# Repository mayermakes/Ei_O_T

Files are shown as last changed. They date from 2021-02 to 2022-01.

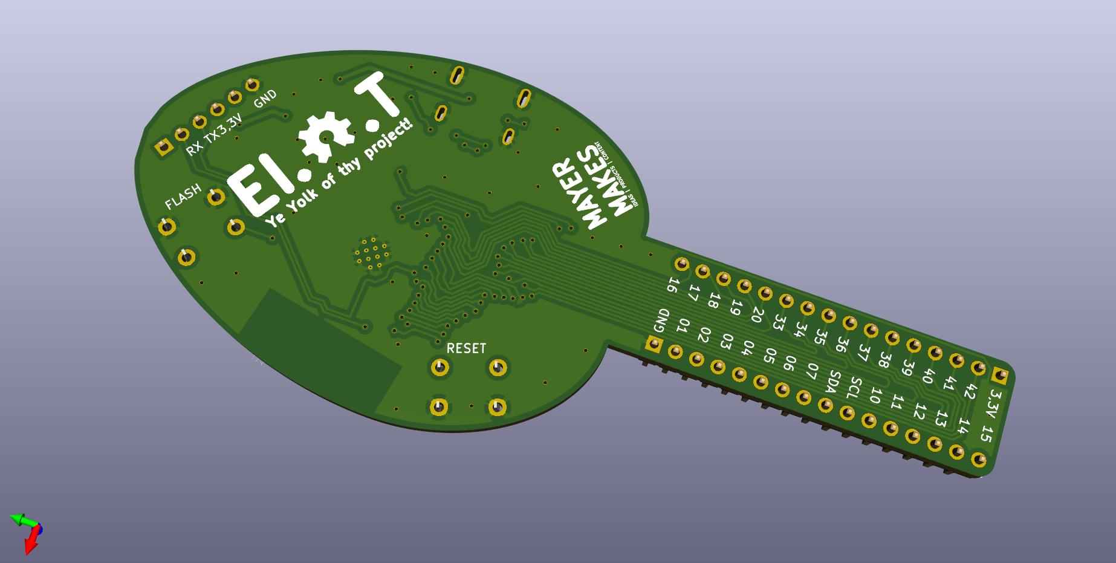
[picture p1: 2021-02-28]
GreenEggs_and_Clem.jpg

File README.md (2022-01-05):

# Ei_O_T
Breadboard Friendly ESP32-S2 Development Kit / Breakout

All EI.O.T Boards are manufactured in either Europe or USA. There are NO genuine Boards made in Asia, and there probably never will be.
This is necessary to ensure quality and safety for the applications developed with our Development Kits and breakout boards.
USB-OTG functionality is built in Hardware wise. 
The Board can be assembled in two ways allowing dominantly left and right handed Developers to optimally use it, also by flipping it upside down you can choose to have the USB cable stick out the top or bottom.

Safety and Handling Notice: 
This product is exclusivelly intended as an utility device for development under laboratory conditions. For use or operation specialist knowledge is required.
Assembly by yourself as askilled technician is required. The provided Firmware is only example code to confirm a correctly executed flashing process.

The project is Licensed CC-BY-SA, the Provided Gerbers are marked with registered Trademarks owned by the original developer or IP owners.
Violation of these rights is not covered by the Open source license or any other license.
If you want to manufacture the Boards for your own private use, you can freely do so. If you intent to bring this design into circulation of any kind you can apply for a distribution license and will be provided an individual version.

The Circuitpython firmware is provided under CC_BY_SA license adhering to the original file it was based on.
You need to follow this guide to be able to flash it:
https://circuitpython.readthedocs.io/en/6.1.x/ports/esp32s2/README.html

For usage with the Arduino IDE please follow the latest tutorial to install the ESP32S2 based boards on Arduino IDE.
To programm the board please choose "ESP32S2DevModule" from the boards list.
Put the board into download mode by holding down the Flash button while pressing reset.
EI.O.T does not automatically reset by design, you need to push the reset button yourself, this is to avoid serial transmittion errors while developing IOT applications.

This evaluation board/kit is intended for use for engineering development, evaluation or demonstration use only. It is not considered by MAYER MAKES e.U. to be a product for End-user /consumer use.  Therefore it may not meet those requirements and is only suitable for use by technically skilled professionals.****

The Files and Documentation are provided as is without any warranty.
MAYER MAKES is an internationally registered Trademark of MAYER MAKES e.U., unauthorized use is prohibited

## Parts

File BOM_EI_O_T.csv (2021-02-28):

Source: | /media/mayermakes/b79b1a1f-57e0-435e-a345-7f3b9296dbeb/kicad/EI_O_T/GreenEggs_and_Clem/GreenEggs_and_Clem.sch
Date: | Fr 26 Feb 2021 21:29:43
Tool: | Eeschema 5.1.5+dfsg1-2build2
Generator: | /usr/share/kicad/plugins/bom_csv_grouped_by_value.py
Component Count: | 16
Individual Components:
Collated Components:
Item | Qty | Reference(s) | Value | LibPart | Footprint | Manufacturer Partnumber | Manufacturer | Supplier | Order Number | Remarks
1 | 1 | C1 | 0,1uF | Device:C | Capacitor_SMD:C_0603_1608Metric_Pad1.05x0.95mm_HandSolder | ~ | Generic
2 | 1 | C2 | 10uF | Device:C | Capacitor_SMD:C_0603_1608Metric_Pad1.05x0.95mm_HandSolder | ~ | Generic
3 | 1 | D1 | LED 0603 | Device:LED | LED_SMD:LED_0603_1608Metric_Pad1.05x0.95mm_HandSolder | ~ | Generic
4 | 1 | J1 | 105450-0101 | 105450-0101:105450-0101 | Molex_USB-C:MOLEX_105450-0101 | 105450-0101 | Molex | Farnell | 2524076 | USB Shielded I/O Receptacle; Type C; Right Angle; Surface Mount; Gold over Nickel
5 | 1 | J2 | Conn_01x06_Female | Connector:Conn_01x06_Female | Connector_PinHeader_2.54mm:PinHeader_1x06_P2.54mm_Vertical | ~ | Generic
6 | 2 | J3, J4 | Conn_01x16 | Connector_Generic:Conn_01x16 | Connector_PinHeader_2.54mm:PinHeader_1x16_P2.54mm_Vertical | ~ | Generic
7 | 2 | R1, R2 | 5k1 | Device:R | Resistor_SMD:R_0603_1608Metric_Pad1.05x0.95mm_HandSolder | ~ | Generic
8 | 2 | R3, R4 | 10k | Device:R | Resistor_SMD:R_0603_1608Metric_Pad1.05x0.95mm_HandSolder | ~ | Generic
9 | 1 | R5 | 220 | Device:R | Resistor_SMD:R_0603_1608Metric_Pad1.05x0.95mm_HandSolder | ~ | Generic
10 | 1 | SW1 | reset | Switch:SW_Push | Button_Switch_THT:SW_PUSH_6mm | ~ | Generic
11 | 1 | SW2 | flash | Switch:SW_Push | Button_Switch_THT:SW_PUSH_6mm | ~ | Generic
12 | 1 | U1 | ESP32-S2-WROOM | ESP32-S2-WROOM:ESP32-S2-WROOM | ESP32S2:XCVR_ESP32-S2-WROOM | ESP32-S2-WROOM(M22S2H3200PH3Q0) | Espressif | Mouser | 356-ESP32S2WRM3200PH
13 | 1 | U2 | MCP1825S-3302E/DB | Regulator_Linear:MCP1825S | Package_TO_SOT_SMD:SOT-223-3_TabPin2 | MCP1825S-3302E/DB | Mikrochip | Farnell | 1578404

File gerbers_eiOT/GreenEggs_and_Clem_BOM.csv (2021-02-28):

ID | Bezeichner | Gehäuse | Stückzahl | Bezeichnung | Anbieter und Referenz
1 | REF** | OSHW-Symbol_6.7x6mm_SilkScreen | 1 | OSHW-Symbol_6.7x6mm_SilkScreen | DO NOT POPULATE
2 | U1 | XCVR_ESP32-S2-WROOM | 1 | ESP32-S2-WROOM | https://www.mouser.at/ProductDetail/Espressif-Systems/ESP32-S2-WROOMM22S2H3200PH3Q0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
3 | C1 | C_0603_1608Metric_Pad1.05x0.95mm_HandSolder | 1 | 0,1uF | https://export.farnell.com/avx/06031c104kat2a/cap-0-1-f-100v-10-x7r-0603/dp/2749806RL?st=0,1uf%200603
4 | C2 | C_0603_1608Metric_Pad1.05x0.95mm_HandSolder | 1 | 10uF | https://export.farnell.com/avx/0603zd106mat2a/cap-10-f-10v-20-x5r-0603/dp/1867954?st=10uf%200603
5 | D1 | LED_0603_1608Metric_Pad1.05x0.95mm_HandSolder | 1 | LED 0603 | https://export.farnell.com/kingbright/kp-1608syck/led-0603-150mcd-yellow/dp/2290330RL?st=led%200603
6 | J1 | MOLEX_105450-0101 | 1 | 105450-0101 | https://export.farnell.com/molex/105450-0101/usb-conn-3-1-usb-type-c-rcpt-surface/dp/2524076?st=105450-0101
7 | J2 | PinHeader_1x06_P2.54mm_Vertical | 1 | Conn_01x06_Female | DO NOT POPULATE
8 | R1,R2 | R_0603_1608Metric_Pad1.05x0.95mm_HandSolder | 2 | 5k1 | https://export.farnell.com/panasonic/erj3ekf5101v/res-5k1-1-0-1w-0603-thick-film/dp/2059378?st=5k1%200603
9 | R3,R4 | R_0603_1608Metric_Pad1.05x0.95mm_HandSolder | 2 | 10k | https://export.farnell.com/vishay/crcw060310k0fkec/res-aec-q200-thick-film-10k-0603/dp/2906637?st=10k%200603
10 | R5 | R_0603_1608Metric_Pad1.05x0.95mm_HandSolder | 1 | 220 | https://export.farnell.com/vishay/crcw0603220rfkea/res-220r-1-0-1w-0603-thick-film/dp/1652857RL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
11 | RESET | SW_PUSH_6mm | 1 | reset | https://export.farnell.com/omron/b3f-1000/switch-spno-0-05a-24v-tht-0-98n/dp/176432?st=omron%20push%20button
12 | FLASH | SW_PUSH_6mm | 1 | flash | https://export.farnell.com/omron/b3f-1000/switch-spno-0-05a-24v-tht-0-98n/dp/176432?st=omron%20push%20button
13 | U2 | SOT-223-3_TabPin2 | 1 | MCP1825S-3002E/DB | https://export.farnell.com/microchip/mcp1825s-3002e-db/ic-ldo-3-0v-500ma-sot-223-3/dp/1578402?st=mcp1825s
14 | J3,J4 | PinHeader_1x16_P2.54mm_Vertical | 2 | Conn_01x16 | https://export.farnell.com/amp-te-connectivity/1-826629-6/header-straight-16way/dp/1248124?st=pinheader%202.54

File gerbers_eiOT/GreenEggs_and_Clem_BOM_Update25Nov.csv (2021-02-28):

ID | Bezeichner | Gehäuse | Stückzahl | Bezeichnung | Anbieter und Referenz
1 | REF** | OSHW-Symbol_6.7x6mm_SilkScreen | 1 | OSHW-Symbol_6.7x6mm_SilkScreen | DO NOT POPULATE
2 | U1 | XCVR_ESP32-S2-WROOM | 1 | ESP32-S2-WROOM | https://www.mouser.at/ProductDetail/Espressif-Systems/ESP32-S2-WROOMM22S2H3200PH3Q0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
3 | C1 | C_0603_1608Metric_Pad1.05x0.95mm_HandSolder | 1 | 0,1uF | local brand 0603(imperial) 0,1uF ceramic cap
4 | C2 | C_0603_1608Metric_Pad1.05x0.95mm_HandSolder | 1 | 10uF | local brand 0603(imperial) 10uF ceramic cap
5 | D1 | LED_0603_1608Metric_Pad1.05x0.95mm_HandSolder | 1 | LED 0603 | local brand 0603(imperial) yellow LED 20ma
6 | J1 | MOLEX_105450-0101 | 1 | 105450-0101 | https://export.farnell.com/molex/105450-0101/usb-conn-3-1-usb-type-c-rcpt-surface/dp/2524076?st=105450-0101
7 | J2 | PinHeader_1x06_P2.54mm_Vertical | 1 | Conn_01x06_Female | DO NOT POPULATE
8 | R1,R2 | R_0603_1608Metric_Pad1.05x0.95mm_HandSolder | 2 | 5k1 | local brand 0603(imperial) 5k1 resistor
9 | R3,R4 | R_0603_1608Metric_Pad1.05x0.95mm_HandSolder | 2 | 10k | local brand 0603(imperial) 10k resistor
10 | R5 | R_0603_1608Metric_Pad1.05x0.95mm_HandSolder | 1 | 220 | local brand 0603(imperial) 220 ohm resistor
11 | RESET | SW_PUSH_6mm | 1 | reset | local brand tht tactile pushbutton DO NOT POPULATE
12 | FLASH | SW_PUSH_6mm | 1 | flash | local brand tht tactile pushbutton DO NOT POPULATE
13 | U2 | SOT-223-3_TabPin2 | 1 | MCP1825S-3002E/DB | https://export.farnell.com/microchip/mcp1825s-3002e-db/ic-ldo-3-0v-500ma-sot-223-3/dp/1578402?st=mcp1825s
14 | J3,J4 | PinHeader_1x16_P2.54mm_Vertical | 2 | Conn_01x16 | local Brand 2,54mm pin header 16 pins DO NOT POPULATE

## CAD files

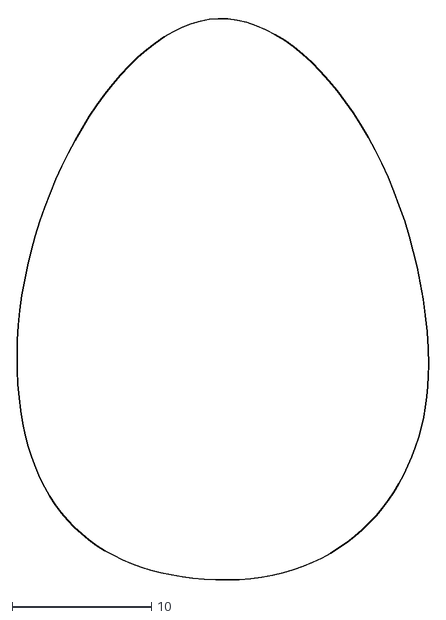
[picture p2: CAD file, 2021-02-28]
egg.dxf
29.8 x 40.6

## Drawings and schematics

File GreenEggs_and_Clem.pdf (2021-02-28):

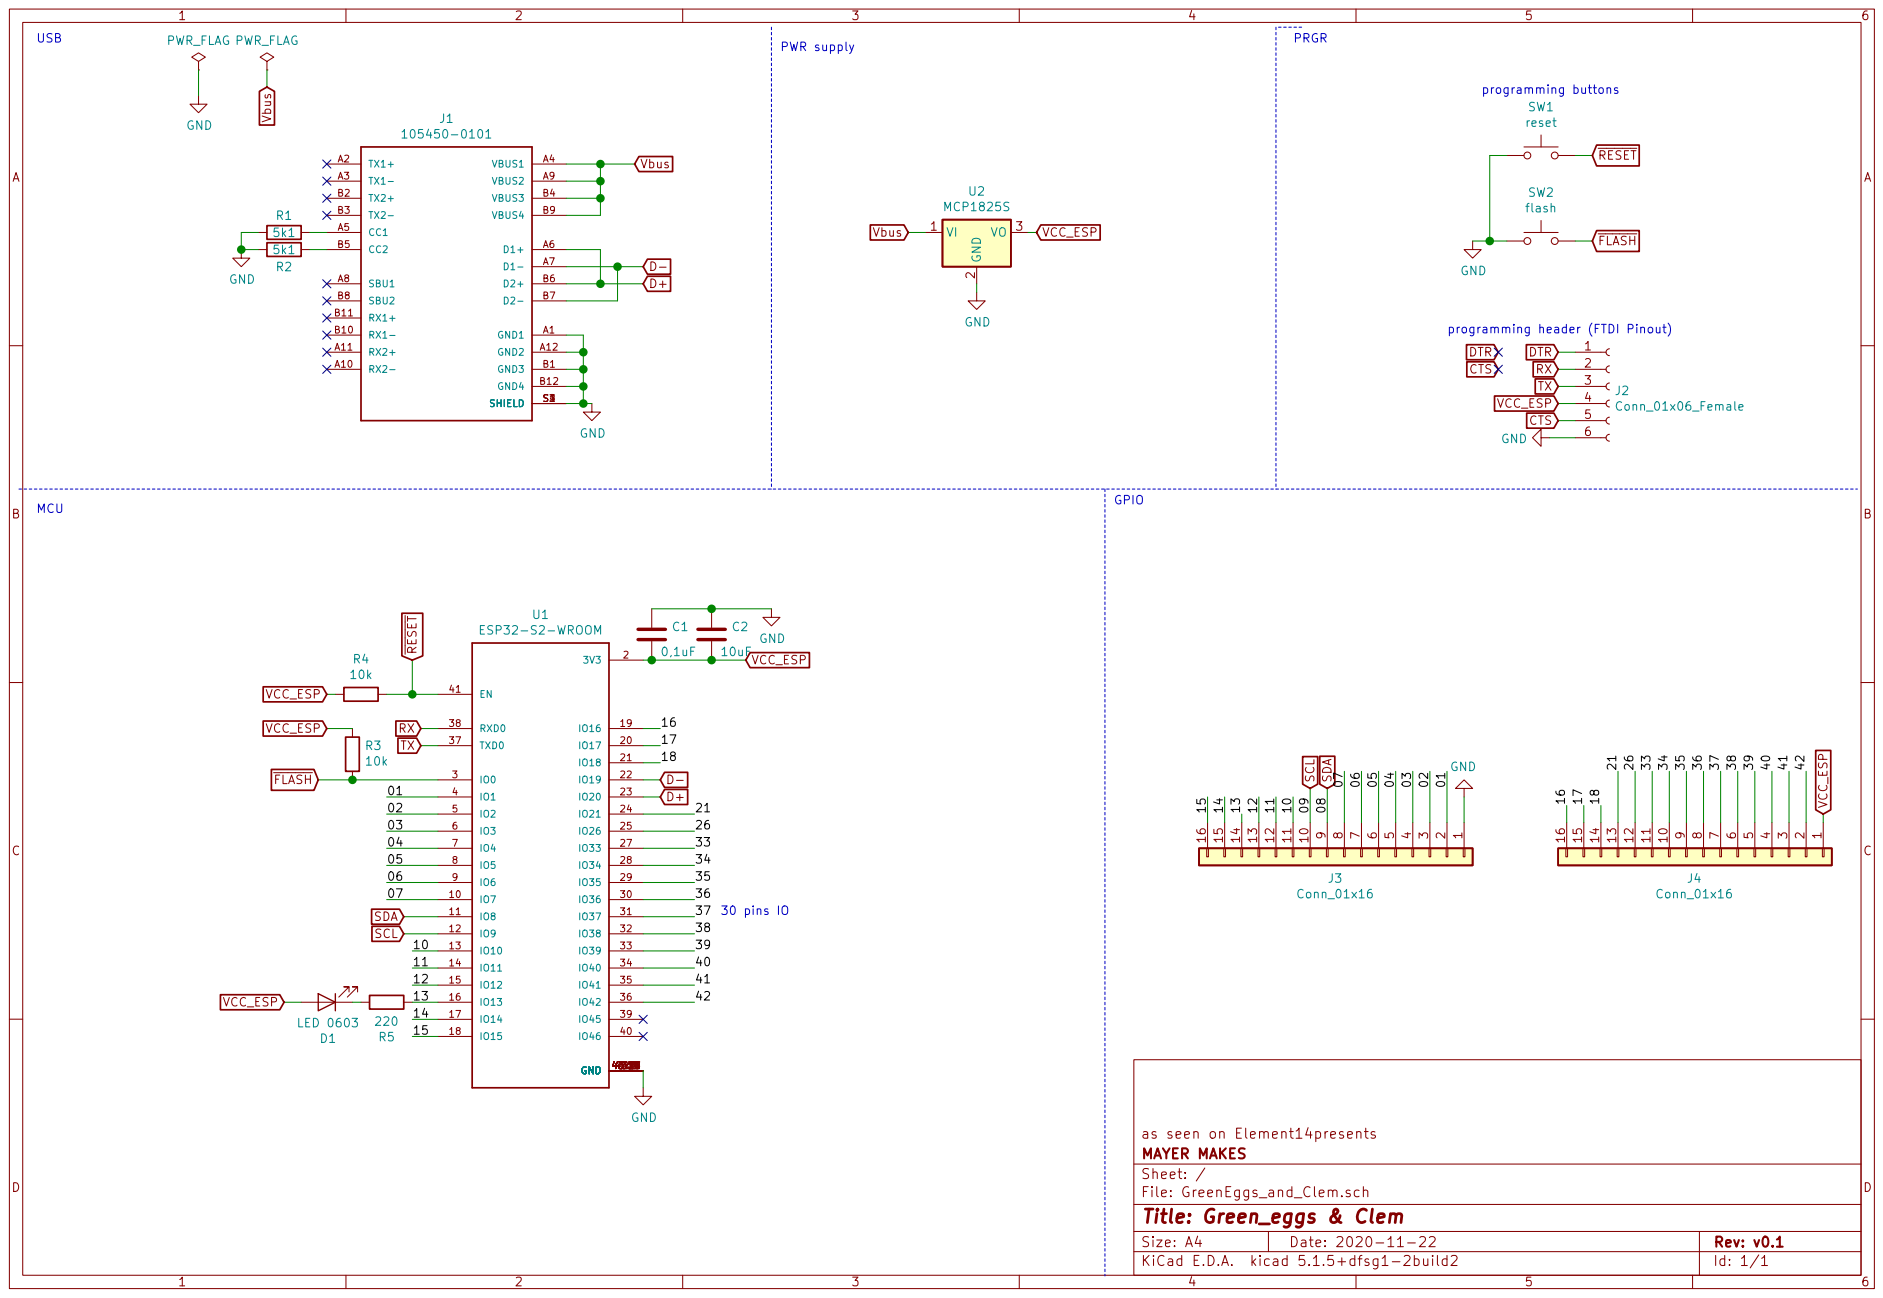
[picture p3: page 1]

programming header (FTDI Pinout)

File: GreenEggs_and_Clem.sch Sheet: / MAYER MAKES as seen on Element14presents

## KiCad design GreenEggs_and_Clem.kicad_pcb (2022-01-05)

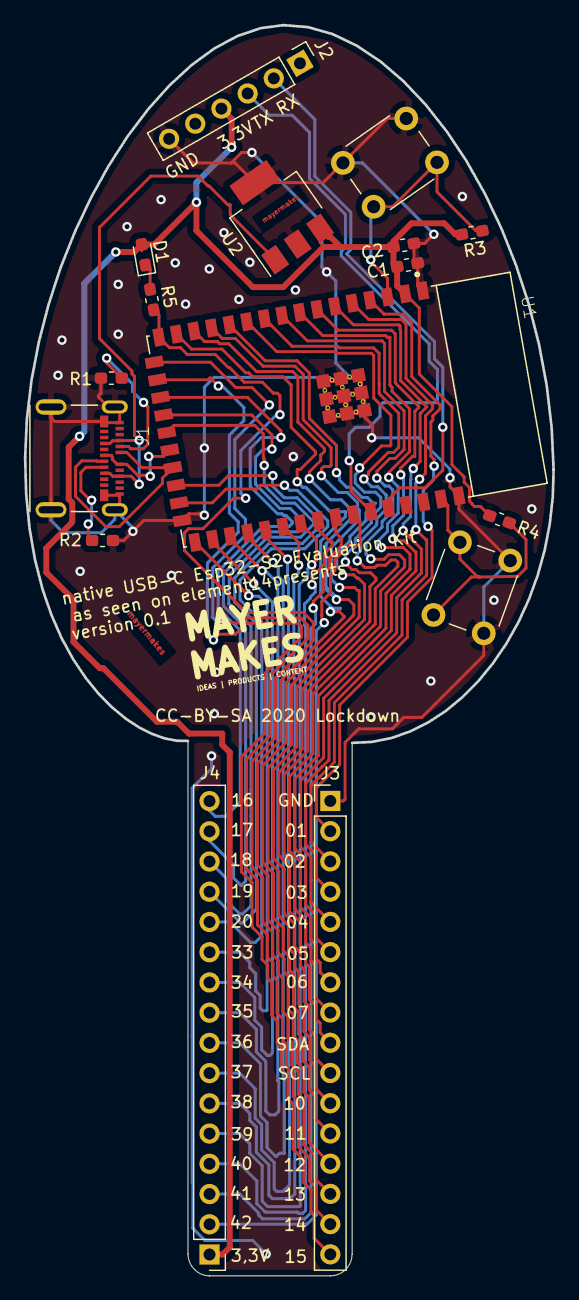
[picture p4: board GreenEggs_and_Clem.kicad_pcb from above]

Board: 2 copper layers, 44.4 x 105.1 mm, 16 parts (0 on the bottom side), 42 nets.

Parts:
C1: 0,1uF; C_0603_1608Metric_Pad1.05x0.95mm_HandSolder
C2: 10uF; C_0603_1608Metric_Pad1.05x0.95mm_HandSolder
D1: LED 0603; LED_0603_1608Metric_Pad1.05x0.95mm_HandSolder
FLASH: flash; SW_PUSH_6mm
J1: 105450-0101; MOLEX_105450-0101
J2: Conn_01x06_Female; PinHeader_1x06_P2.54mm_Vertical
J3, J4: Conn_01x16; PinHeader_1x16_P2.54mm_Vertical
R1, R2: 5k1; R_0603_1608Metric_Pad1.05x0.95mm_HandSolder
R3, R4: 10k; R_0603_1608Metric_Pad1.05x0.95mm_HandSolder
R5: 220; R_0603_1608Metric_Pad1.05x0.95mm_HandSolder
RESET: reset; SW_PUSH_6mm
U1: ESP32-S2-WROOM; XCVR_ESP32-S2-WROOM
U2: MCP1825S; SOT-223-3_TabPin2

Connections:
/01: J3.2, U1.4
/02: J3.3, U1.5
/03: J3.4, U1.6
/04: J3.5, U1.7
/05: J3.6, U1.8
/06: J3.7, U1.9
/07: J3.8, U1.10
/10: J3.11, U1.13
/11: J3.12, U1.14
/12: J3.13, U1.15
/13: J3.14, R5.2, U1.16
/14: J3.15, U1.17
/15: J3.16, U1.18
/16: J4.16, U1.19
/17: J4.15, U1.20
/18: J4.14, U1.21
/21: J4.13, U1.24
/26: J4.12, U1.25
/33: J4.11, U1.27
/34: J4.10, U1.28
/35: J4.9, U1.29
/36: J4.8, U1.30
/37: J4.7, U1.31
/38: J4.6, U1.32
/39: J4.5, U1.33
/40: J4.4, U1.34
/41: J4.3, U1.35
/42: J4.2, U1.36
D+: J1.A6, J1.B6, U1.23
D-: J1.A7, J1.B7, U1.22
GND: C1.1, C2.1, FLASH.1, J1.A1, J1.A12, J1.B1, J1.B12, J1.S1, J1.S2, J1.S3, J1.S4, J2.6, J3.1, R1.2, R2.2, RESET.1, U1.1, U1.26, U1.42, U1.43.1, U1.43.2, U1.43.3, U1.43.4, U1.43.5, U1.43.6, U1.43.7, U1.43.8, U1.43.9, U1.43.10, U1.43.11, U1.43.12, U1.43.13, U1.43.14, U1.43.15, U1.43.16, U1.43.17, U1.43.18, U1.43.19, U1.43.20, U1.43.21, U2.2
unnamed: D1.1, R5.1
unnamed: J1.A5, R1.1
unnamed: J1.B5, R2.1
RX: J2.2, U1.38
SCL: J3.10, U1.12
SDA: J3.9, U1.11
TX: J2.3, U1.37
VCC_ESP: C1.2, C2.2, D1.2, J2.4, J4.1, R3.2, R4.2, U1.2, U2.3
Vbus: J1.A4, J1.A9, J1.B4, J1.B9, U2.1
~FLASH: FLASH.2, R3.1, U1.3
~RESET: R4.1, RESET.2, U1.41

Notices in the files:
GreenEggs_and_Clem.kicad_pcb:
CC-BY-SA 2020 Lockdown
